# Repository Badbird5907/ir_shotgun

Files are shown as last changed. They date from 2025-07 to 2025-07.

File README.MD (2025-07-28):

# IR Shotgun
This is a IR shotgun (blaster) for the flipper zero that uses 8x APTD3216F3C-P22 infrared LEDs to absolutely FLOOD a room with infrared light.

## How does it work?
The flipper zero drives the A7 pin with PWM, which in turn drives the AO3400A MOSFET. The MOSFET then turns on and off the IR LEDs.

## How does this compare to the Rabbit Labs IR Blaster?
This blaster is (I think) a bit more powerful, and more directional compared to the Rabbit Labs IR Blaster.

## Design choices
- Instead of using 1x3 pin headers, I used 2x3 headers to provide better structural support for the blaster PCB.
- I used the AO3400A MOSFET over the 2N7000 because it's able to handle more current.
- My calculations for the resistor values for the LEDs (70 ohm -> 68 ohm) were based on the DC Forward Current of 50mA and not the peak forward current of 1200mA.

## Pictures
render
blaster back
blaster
base

## BOM
|Name |Qty |Price Per (USD)|Total (USD)|Link |
|---|---|---|---|---|
|90 Degree header |1 |$0.67 |$0.67 |https://www.digikey.ca/en/products/detail/w%C3%BCrth-elektronik/61300621021/4846834 |
|0.1uF 0805 cap |1 |$0.08 |$0.08 |https://www.digikey.ca/en/products/detail/samsung-electro-mechanics/CL21B104KBCNNNC/3886661|
|10uF 1206 cap |1 |$0.08 |$0.08 |https://www.digikey.ca/en/products/detail/samsung-electro-mechanics/CL31B106KAHNNNE/3887462|
|IR LED |8 |$0.52 |$4.16 |https://www.digikey.ca/en/products/detail/kingbright/APTD3216F3C-P22/8591562 |
|AO3400A MOSFET |1 |$0.46 |$0.46 |https://www.digikey.ca/en/products/detail/alpha-omega-semiconductor-inc/AO3400A/1855772 |
|68 ohm res |4 |$0.60 |$2.40 |https://www.digikey.ca/en/products/detail/susumu/HRG3216P-68R0-D-T1/5762544 |
|10k res |1 |$0.10 |$0.10 |https://www.digikey.ca/en/products/detail/stackpole-electronics-inc/RMCF0805FT10K0/1760676 |
|15mm pin headers |1 |$3.43 |$3.43 |https://www.aliexpress.com/item/1005006783391171.html |
|Blaster PCB (JLC, LeadFree HASL) |1 |$5.20 |$5.20 | |
|Base PCB (JLC, LeadFree HASL) |1 |$5.20 |$5.20 | |
|TOTAL | | |$21.78 | |
|NOTE: Most of the resistors/caps here cost more in packages of one than in packages of 10+, I'd suggest ordering 10 of each| | | | |
| | | | | |
| |USD | | | |
|JLC - DHL |$17.50| | | |
|DigiKey |$5.84 | | | |
| | | | | |
| | | | | |
|Grand Total | | |$45.12 | |
                                                                                  |      |               |           |                                                                                           |
|Shipping

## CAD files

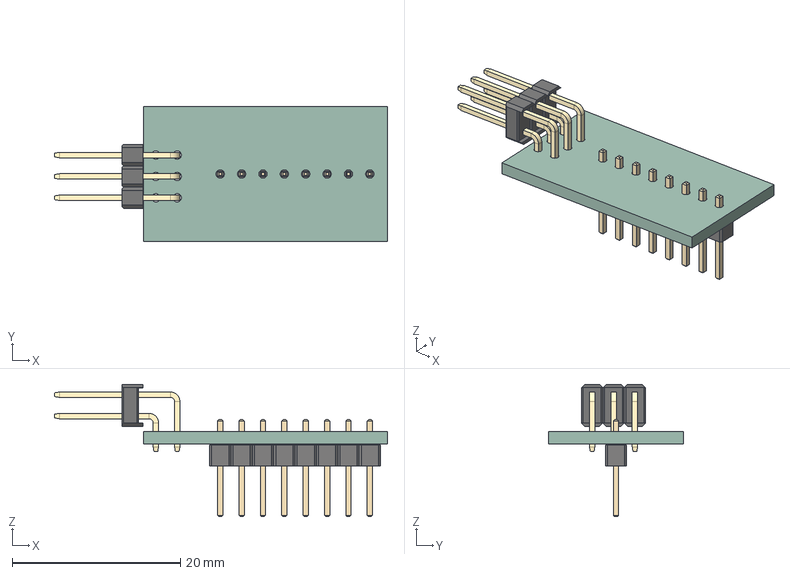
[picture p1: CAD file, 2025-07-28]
base/base.step
39.6 x 16.0 x 15.7 mm
connector
PinHeader_1x08_P2.54mm_Vertical
base_PCB

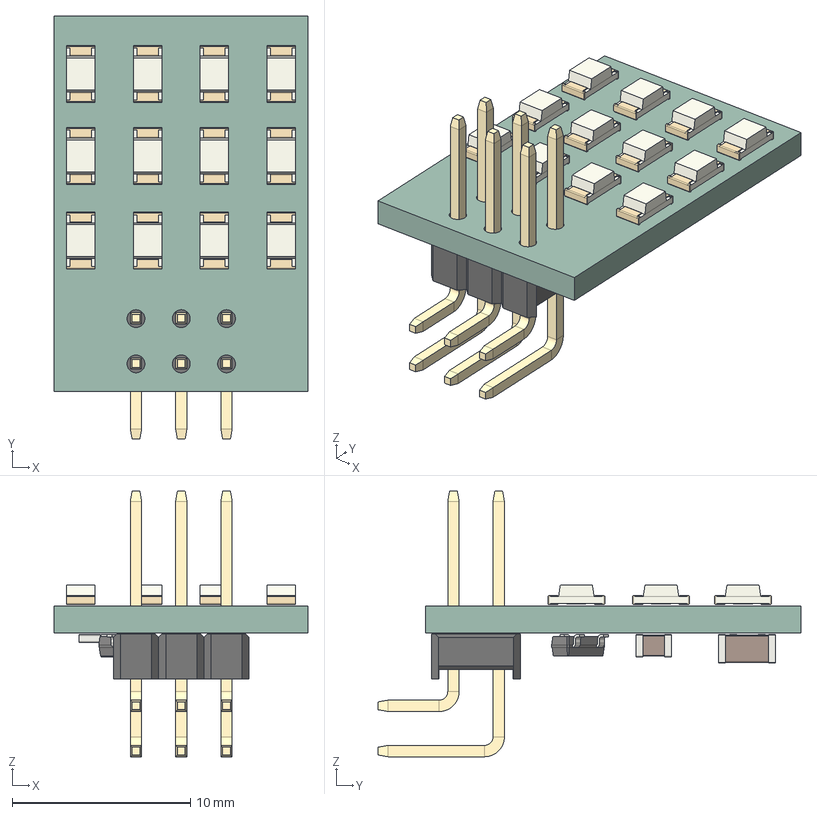
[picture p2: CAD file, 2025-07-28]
blaster/ir_shotgun.step
14.2 x 23.7 x 14.9 mm
LED_1206_3216Metric x 12
C_0805_2012Metric x 2
C_1206_3216Metric
connector
SOT-23
R_0805_2012Metric
ir_shotgun_PCB

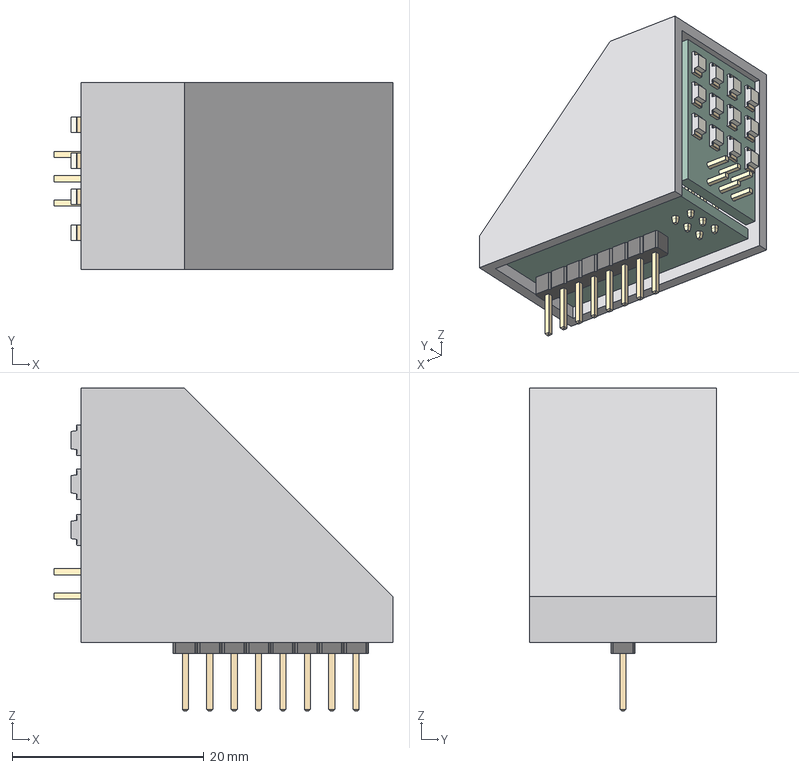
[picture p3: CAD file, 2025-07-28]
case.step
35.3 x 19.5 x 33.6 mm
LED_1206_3216Metric x 12
C_0805_2012Metric x 2
C_1206_3216Metric
SOT-23
R_0805_2012Metric
ir_shotgun_PCB
connector
PinHeader_1x08_P2.54mm_Vertical
base_PCB

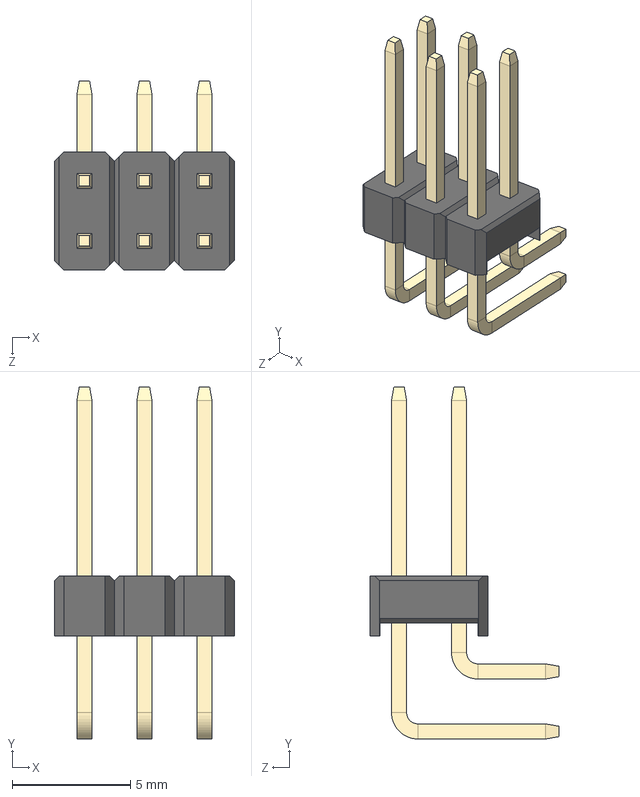
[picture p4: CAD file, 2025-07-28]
connector.step
7.63 x 14.9 x 8.00 mm

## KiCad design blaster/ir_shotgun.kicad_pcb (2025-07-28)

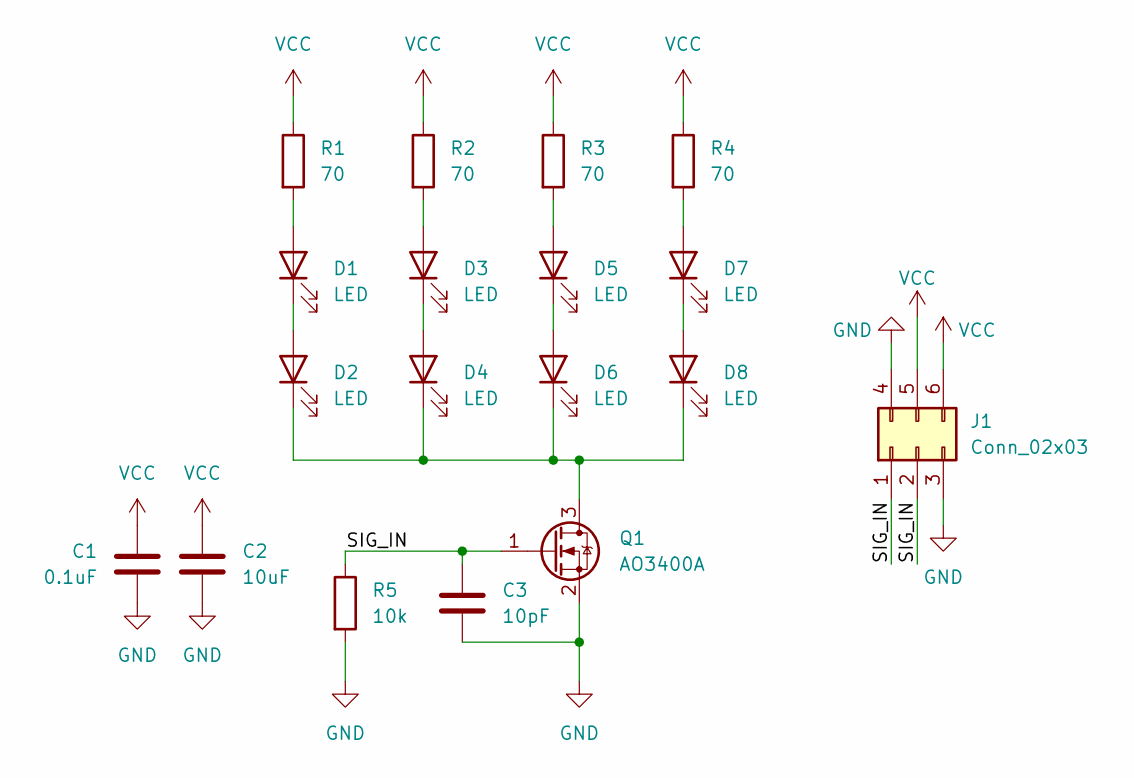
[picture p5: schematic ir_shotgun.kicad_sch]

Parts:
C1: 0.1uF; C_0805_2012Metric
C2: 10uF; C_1206_3216Metric
C3: 10pF; C_0805_2012Metric
D1, D2, D3, D4, D5, D6, D7, D8: LED; LED_1206_3216Metric
J1: Conn_02x03; PinHeader_2x03_P2.54mm_Vertical
Q1: AO3400A; SOT-23
R1, R2, R3, R4: 70; LED_1206_3216Metric
R5: 10k; R_0805_2012Metric

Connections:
/SIG_IN: C3.1, J1.1, J1.2, Q1.1 (G), R5.1
GND: C1.2, C2.2, C3.2, J1.3, J1.4, Q1.2 (S), R5.2
unnamed: D1.2 (A), R1.2
unnamed: D1.1 (K), D2.2 (A)
unnamed: D2.1 (K), D4.1 (K), D6.1 (K), D8.1 (K), Q1.3 (D)
unnamed: D3.2 (A), R2.2
unnamed: D3.1 (K), D4.2 (A)
unnamed: D5.2 (A), R3.2
unnamed: D5.1 (K), D6.2 (A)
unnamed: D7.2 (A), R4.2
unnamed: D7.1 (K), D8.2 (A)
VCC: C1.1, C2.1, J1.5, J1.6, R1.1, R2.1, R3.1, R4.1

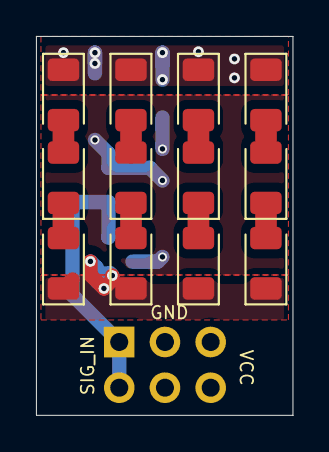
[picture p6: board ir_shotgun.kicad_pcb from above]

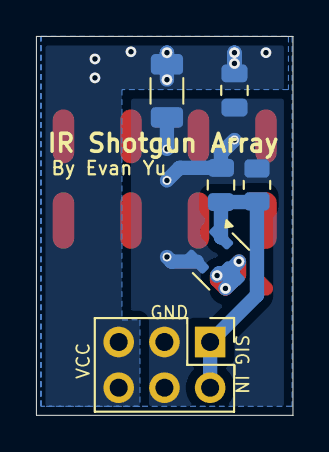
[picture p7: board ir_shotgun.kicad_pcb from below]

Board: 2 copper layers, 14.2 x 21.0 mm, 18 parts (6 on the bottom side), 12 nets.

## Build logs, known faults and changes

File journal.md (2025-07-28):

# July 26
Time spent: 5h

Looked at different IR LEDs that could fit my use case. I ended up on using 8 of the APTD3216F3C-P22, which should fit nicely into the power budget of 5W

I also designed the PCB, which needed some kind of 90 degree connector. I initially came up with this design:
design

However, I realized it's really jank and instead decided to switch it out for a 90 degree pin header.


# July 27
Time spent: 3h

I tweaked the design, sourced parts on digikey, and worked on the bom.
Also cadded a case:
